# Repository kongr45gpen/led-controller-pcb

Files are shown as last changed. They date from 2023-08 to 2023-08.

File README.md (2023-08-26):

# led-controller-pcb

A PCB to control LEDs (up to 5 channels) using PWM, based on an Espressif ESP32-C6 development board.

Do you want to control your LEDs through Wi-Fi, Bluetooth or Zigbee, but you don't have 100€ lying around? This project is for you!
## Images

 

## Features

- 5 PWM **output channels**
- 5 **switch MOSFETS** (up to 8A)
- VIN **up to 28V**
- ESP32-C6 controllable through **USB, Wi-Fi, Bluetooth 5 (LE), IEEE 802.15.4**
- Support for RGB, RGBW, RGBWW/CW, WS2812B, and other configurations
- Control through MQTT, HomeAssistant
- **Non**-isolated input
- Fully open-source software and hardware
- 6.25 × 5 cm
- Not battle tested, so might stop working randomly

## Software

You can write your software using any framework you prefer. This board is built and will work out of the box for the [kongr45gpen/ledstripesp32](https://github.com/kongr45gpen/ledstripesp32) project specifically.

## Bill of Materials

This board is meant to function as a **controller** (generating low-power PWM signals from a network/wired input), as a **dimmer** (switching high-power LED lights on/off based on the input signal) or both.

The **controller** function is based on the [ESP32-C6-DevKitC-1](https://docs.espressif.com/projects/espressif-esp-dev-kits/en/latest/esp32c6/esp32-c6-devkitc-1/index.html) development board, but other ESP32 development boards should be also usable (not tested).

The **dimmer** function relies on a few MOSFETs to control the current flow from the output.

The rest of the components are mostly optional and slightly improve the functionality of the board (connectors, pull-down resistors etc). The user can choose whichever components they need and assemble the board to their preference. Many components (e.g. DC barrel jack, headers, passives) may be replaceable with cheaper generic alternatives.

An all-around configuration should cost ~20€, and adding a screen, voltage regulator and detachable headers should move the price up to ~35€.

A total project cost for a simple RGB led control system could be: 5m 5050 12V RGB LED strip (10€) + 12V 1A power supply (10€) + PCB (6€) + components (20€) = 46€.

With example parts and prices from Mouser:

| Ref | Part | Qu.| CONT. | DIM. | Description | Price |
| :-- | :--- | :---: | :---: | :----: | --- | ----: |
| Brd1 | 4-pin I2C SSD1306 | 1 | ❓ | | Debugging info screen | 3€ |
| C1 | C 100nF 0603 (1608 metric) | 1 | | ✔️ | Decoupling capacitor | [0.1€](https://www.mouser.com/ProductDetail/581-04026D104KAT4A) |
| J1 | CUI PJ-063AH | 1 | | ❓ | VIN Barrel connector | [1.5€](https://www.mouser.com/ProductDetail/490-PJ-063AH) |
| J2 | Molex SL 171971-0002 | 1 | | ❓ | VIN Header connector | [0.8€](https://www.mouser.com/ProductDetail/Molex/171971-0002?qs=lc2O%252BfHJPVZiIVvtLkRJ0A%3D%3D) |
| J3 | Molex SL 171971-0007 | 1 | ❓ | ❓ | PWM input/output connector (5 pins + GND) | [1.5€](https://www.mouser.com/ProductDetail/Molex/171971-0007?qs=lc2O%252BfHJPVYTelce0YNW%252BQ%3D%3D) |
| J4 | 5mm 6-pin screw terminal | 1 | | ✔️ | Power output (5 pins + VDD) | [0.9€](https://www.mouser.com/ProductDetail/490-TB003-500-P06BE) |
| J5 | Molex SL 171971-0003 | 1 | ❓ | | Addressable LED output | [1.1€](https://www.mouser.com/ProductDetail/Molex/171971-0003?qs=lc2O%252BfHJPVYq9zLgxhm5jg%3D%3D) |
| LED1..5 | 0805 (2012 metric) LED | 5 | ❓ | ❓ | Indicator LEDs for PWM | [1.25€](https://www.mouser.com/ProductDetail/859-LTST-C170KFKT) |
| LED\_POWER1 | 0805 (2012 metric) LED | 1 | | ❓ | Indicator LED for VDD | [0.25€](https://www.mouser.com/ProductDetail/859-LTST-C170KFKT) |
| Q1..5 | IRLTS6342 (N-MOSFET) | 5 | | ✔️ | Control transistors (use as many as needed) | [1.7€](https://www.mouser.com/ProductDetail/Infineon-Technologies/IRLTS6342TRPBF?qs=8jYDHybYAxsDJhh9ct3B2Q%3D%3D) |
| R1..6 | R 15kΩ 0603 (1608 metric) | 6 | | ❓ | LED series resistors (use as many as needed) | [0.1€](https://www.mouser.com/ProductDetail/603-RC0603FR-0715KL) |
| Rpd1..5 | R 100kΩ 0603 (1608 metric) | 5 | ❓ | ❓ | Pull-down resistors to keep output off when disconnected | [0.1€](https://www.mouser.com/ProductDetail/603-RC0402FR-07100KL) |
| SW1 | PTS647SM70SMTR2LFS | 1 | ❓ | | ESP32 input switch | [0.2€](https://www.mouser.com/ProductDetail/CK/PTS647SM70SMTR2LFS?qs=PqoDHHvF64%252Bxl5nIb9IaOw%3D%3D) |
| U1 | ESP32-C6-DevKitC-1 | 1 | ✔️ | | ESP32 development kit | [8€](https://www.mouser.com/ProductDetail/356-ESP32C6DKC1N8) |
| VR1 | Wurth 1769405241 | 1 | ❓ | | Voltage regulator to provide 5V to ESP32 from VIN | [5€](https://www.mouser.com/ProductDetail/710-1769405241) |

### Extra Accessories

| Part | Quantity | CONTROLLER | DIMMER | Description | Price |
|---|:---:|:---:|:---:|---|---:|
| 4-pin header | 1 | ❓ |  | For screen (`Brd1`) | [0.7€](https://www.mouser.com/ProductDetail/200-CES10402TS) |
| 16-pin-header | 2 | ❓ | | For ESP32 (`U1`) | [5€](https://www.mouser.com/ProductDetail/200-CES11601TS) |
| Molex 14-60-0024 | 1 | | ❓ | Wire plug for `J2` | [0.4€](https://www.mouser.com/ProductDetail/538-14-60-0024) |
| Molex 14-60-0072 | 1 | ❓ | ❓ | Wire plug for `J3` | [1.5€](https://www.mouser.com/ProductDetail/538-14-60-0072) |
| Molex 14-56-7032 | 1 | ❓ | | Wire plug for `J5` | [0.7€](https://www.mouser.com/ProductDetail/538-14-56-7032) |

### Solder Bridges

Some solder bridges/solder jumpers may need to be soldered before any operation can take place.

| Ref | Pins | CONTROLLER | DIMMER | Description |
| :-- | :--: | :---: | :----: | :--- |
| JP1 | 3 | | ✔️ | Controls the source of `VDD` for the LED power output. Bridge 2-1 to connect to `5V`. Bridge 2-3 to connect to `VIN` (J1, J2). |
| JP2 | 3 | ❓ | | Controls the voltage source (typically 5V) for the addressable strip. Bridge 2-1 to connect to `5V`. Bridge 2-3 to connect to `VIN` (J1, J2). |
| JP3 | 2 | | ✔️ | Bridge to connect power ground with digital ground. **Must** solder for proper operation.  |
| JP4 | 2 | ❓ | | Bridge to connect VR1 output to 5V. Must solder to enable voltage regulation from VIN to ESP32 5V. Keep desoldered during debugging to prevent damaging your equipment.  |
| JPout1..5 | 2 | | ✔️ | Bridge to connect transistor outputs to output connector. You can alternatively wire a series resistor here for your output, if needed. |

### Example configurations

**All-in-one controller, from Wi-Fi to RGB LED strip**:
- C1, J1 to connect an external 12V power supply
- VR1 to convert the external 12V to 5V for the ESP32
- LED1..3, LED_POWER1, R1..3, R6 for debugging indicators
- Q1..3 as amplifiers
- Rpd1..3 to prevent lights from going up during boot
- J4 to screw LED strip wires
- U1 for control
- Bridge JP1 (2-3), JP3, JPout1..3. After uploading code, bridge JP4.
- BOM cost: **18€**

**Addressable strip controller with debugging screen**:
- No need for power input, as the ESP32 dev board already has USB-C connections
- U1 for control
- J5 connector to output addressable LED data
- J5 wire plug to solder on addressable LED
- Brd1 screen + 4-pin header to allow detaching it
- Bridge JP2 (2-1)
- BOM cost: **6€**

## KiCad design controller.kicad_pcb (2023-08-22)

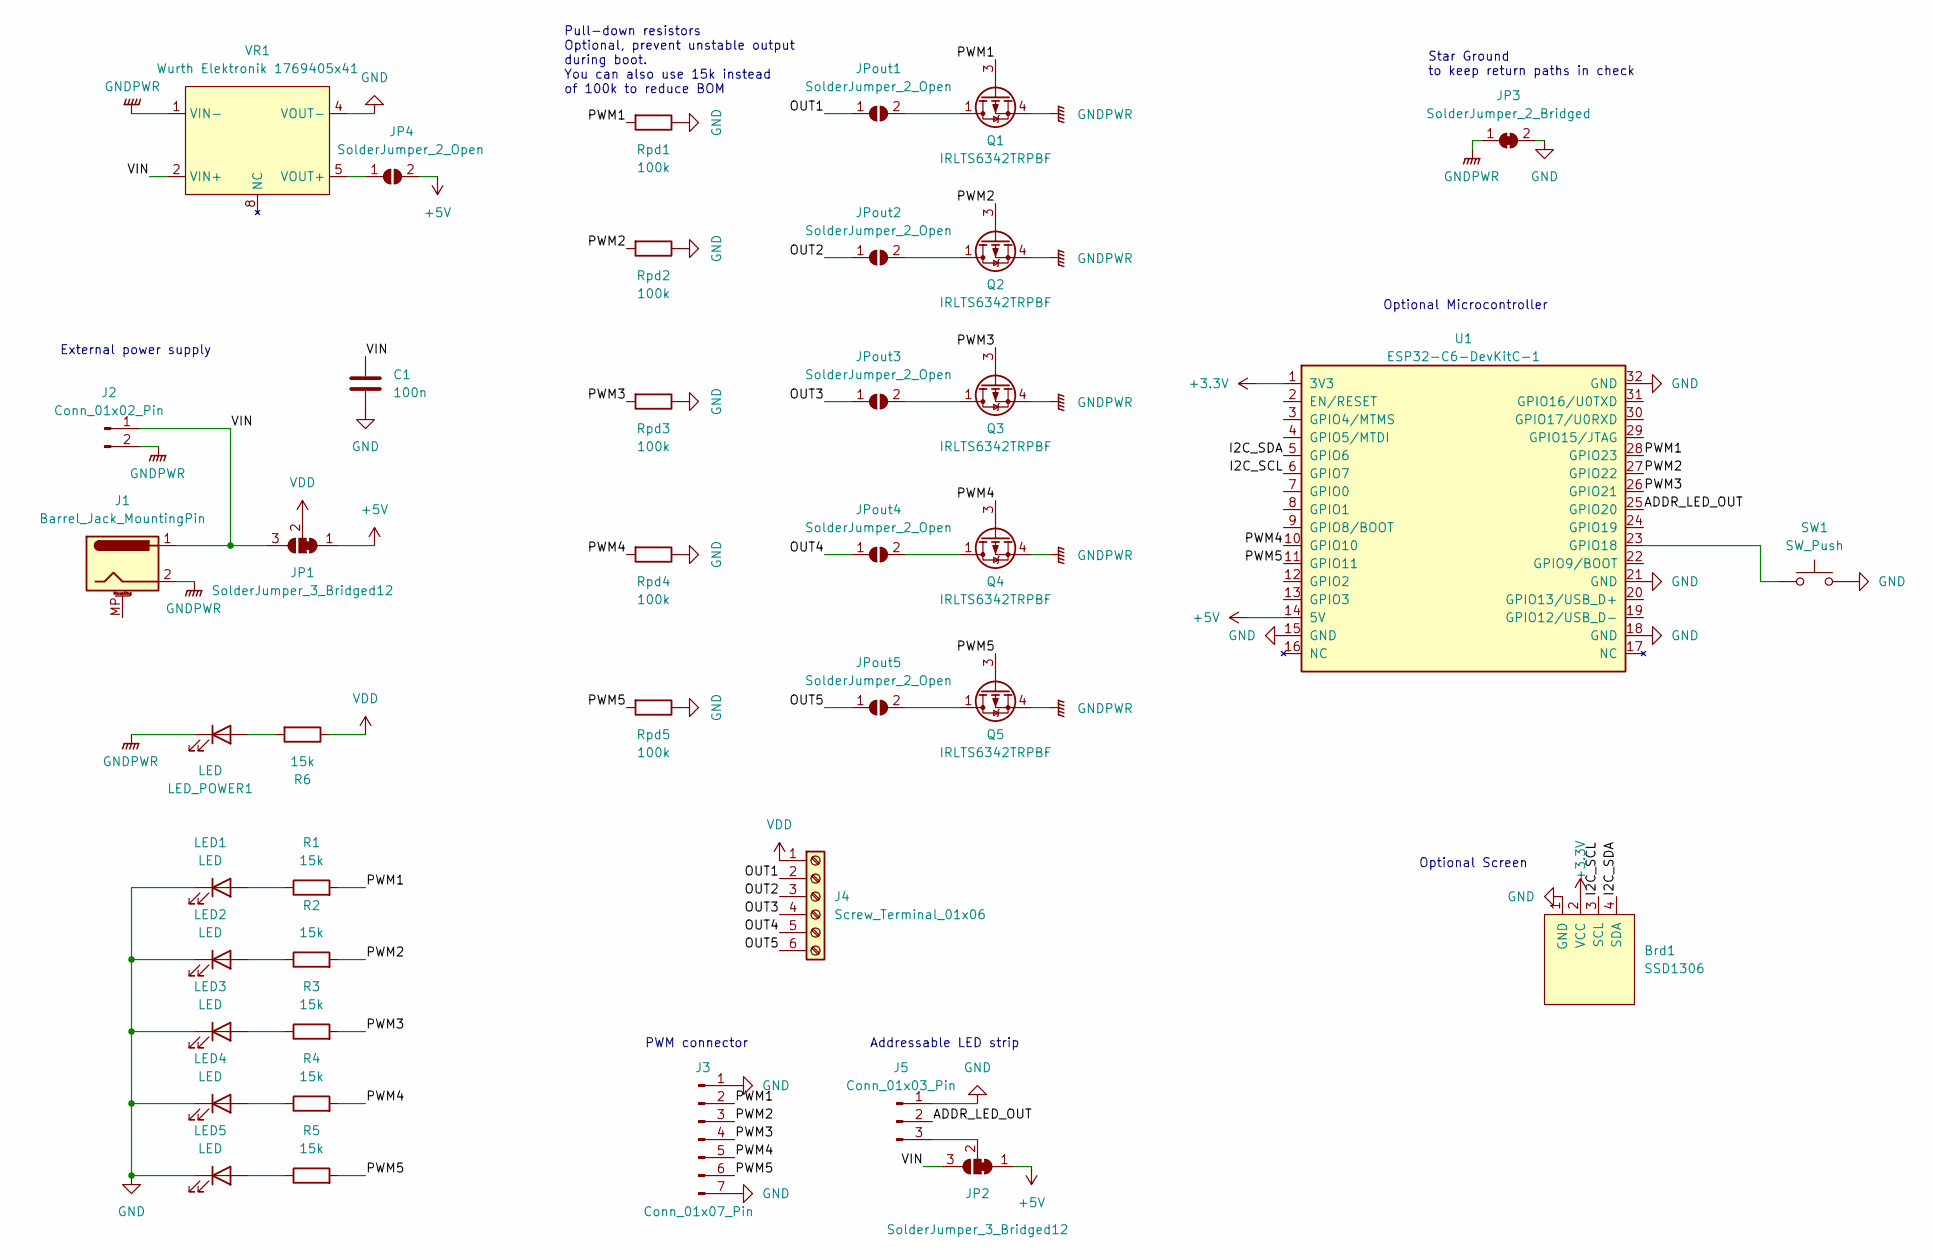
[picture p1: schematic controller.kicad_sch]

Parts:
Brd1: SSD1306; 128x64OLED
C1: 100n; C_0603_1608Metric_Pad1.08x0.95mm_HandSolder
J1: Barrel_Jack_MountingPin; BarrelJack_CUI_PJ-063AH_Horizontal_CircularHoles
J2: Conn_01x02_Pin; Molex_SL_171971-0002_1x02_P2.54mm_Vertical
J3: Conn_01x07_Pin; Molex_SL_171971-0007_1x07_P2.54mm_Vertical
J4: Screw_Terminal_01x06; TerminalBlock_RND_205-00005_1x06_P5.00mm_Horizontal
J5: Conn_01x03_Pin; Molex_SL_171971-0003_1x03_P2.54mm_Vertical
JP1, JP2: SolderJumper_3_Bridged12; SolderJumper-3_P1.3mm_Open_RoundedPad1.0x1.5mm_NumberLabels
JP3: SolderJumper_2_Bridged; SolderJumper-2_P1.3mm_Bridged2Bar_Pad1.0x1.5mm
JP4: SolderJumper_2_Open; SolderJumper-2_P1.3mm_Open_RoundedPad1.0x1.5mm
JPout1, JPout2, JPout3, JPout4, JPout5: SolderJumper_2_Open; SolderJumper-2_P1.3mm_Open_TrianglePad1.0x1.5mm
LED1, LED2, LED3, LED4, LED5: LED; LED_0805_2012Metric_Pad1.15x1.40mm_HandSolder
LED_POWER1: LED; LED_0805_2012Metric_Pad1.15x1.40mm_HandSolder
Q1, Q2, Q3, Q4, Q5: IRLTS6342TRPBF; TSOP-6_1.65x3.05mm_P0.95mm
R1, R2, R3, R4, R5, R6: 15k; R_0603_1608Metric_Pad0.98x0.95mm_HandSolder
Rpd1, Rpd2, Rpd3, Rpd4, Rpd5: 100k; R_0603_1608Metric_Pad0.98x0.95mm_HandSolder
SW1: SW_Push; SWITCH-4
U1: ESP32-C6-DevKitC-1
VR1: Wurth Elektronik 1769405x41; 1769405x41

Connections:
+3.3V: Brd1.2 (VCC), U1.1 (3V3)
+5V: JP1.1 (A), JP2.1 (A), JP4.2 (B), U1.14 (5V)
/ADDR_LED_OUT: J5.2, U1.25 (GPIO20)
/I2C_SCL: Brd1.3 (SCL), U1.6 (GPIO7)
/I2C_SDA: Brd1.4 (SDA), U1.5 (GPIO6)
/OUT1: J4.2, JPout1.1 (A)
/OUT2: J4.3, JPout2.1 (A)
/OUT3: J4.4, JPout3.1 (A)
/OUT4: J4.5, JPout4.1 (A)
/OUT5: J4.6, JPout5.1 (A)
/PWM1: J3.2, Q1.3 (G), R1.2, Rpd1.2, U1.28 (GPIO23)
/PWM2: J3.3, Q2.3 (G), R2.2, Rpd2.2, U1.27 (GPIO22)
/PWM3: J3.4, Q3.3 (G), R3.2, Rpd3.2, U1.26 (GPIO21)
/PWM4: J3.5, Q4.3 (G), R4.2, Rpd4.2, U1.10 (GPIO10)
/PWM5: J3.6, Q5.3 (G), R5.2, Rpd5.2, U1.11 (GPIO11)
/VIN: C1.1, J1.1, J2.1, JP1.3 (B), JP2.3 (B), VR1.2 (VIN+)
GND: Brd1.1 (GND), C1.2, J3.1, J3.7, J5.1, JP3.2 (B), LED1.1 (K), LED2.1 (K), LED3.1 (K), LED4.1 (K), LED5.1 (K), Rpd1.1, Rpd2.1, Rpd3.1, Rpd4.1, Rpd5.1, SW1.2, SW1.4, U1.15 (GND), U1.18 (GND), U1.21 (GND), U1.32 (GND), VR1.4 (VOUT-)
GNDPWR: J1.2, J2.2, JP3.1 (A), LED_POWER1.1 (K), Q1.4 (S), Q2.4 (S), Q3.4 (S), Q4.4 (S), Q5.4 (S), VR1.1 (VIN-)
unnamed: J5.3, JP2.2 (C)
unnamed: JP4.1 (A), VR1.5 (VOUT+)
unnamed: JPout1.2 (B), Q1.1 (D), Q1.2 (D), Q1.5 (D), Q1.6 (D)
unnamed: JPout2.2 (B), Q2.1 (D), Q2.2 (D), Q2.5 (D), Q2.6 (D)
unnamed: JPout3.2 (B), Q3.1 (D), Q3.2 (D), Q3.5 (D), Q3.6 (D)
unnamed: JPout4.2 (B), Q4.1 (D), Q4.2 (D), Q4.5 (D), Q4.6 (D)
unnamed: JPout5.2 (B), Q5.1 (D), Q5.2 (D), Q5.5 (D), Q5.6 (D)
unnamed: LED1.2 (A), R1.1
unnamed: LED2.2 (A), R2.1
unnamed: LED3.2 (A), R3.1
unnamed: LED4.2 (A), R4.1
unnamed: LED5.2 (A), R5.1
unnamed: LED_POWER1.2 (A), R6.2
unnamed: SW1.1, SW1.3, U1.23 (GPIO18)
VDD: J4.1, JP1.2 (C), R6.1

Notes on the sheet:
External power supply
Star Ground to keep return paths in check
Pull-down resistors Optional, prevent unstable output during boot. You can also use 15k instead of 100k to reduce BOM
Addressable LED strip
Optional Microcontroller
Optional Screen
PWM connector

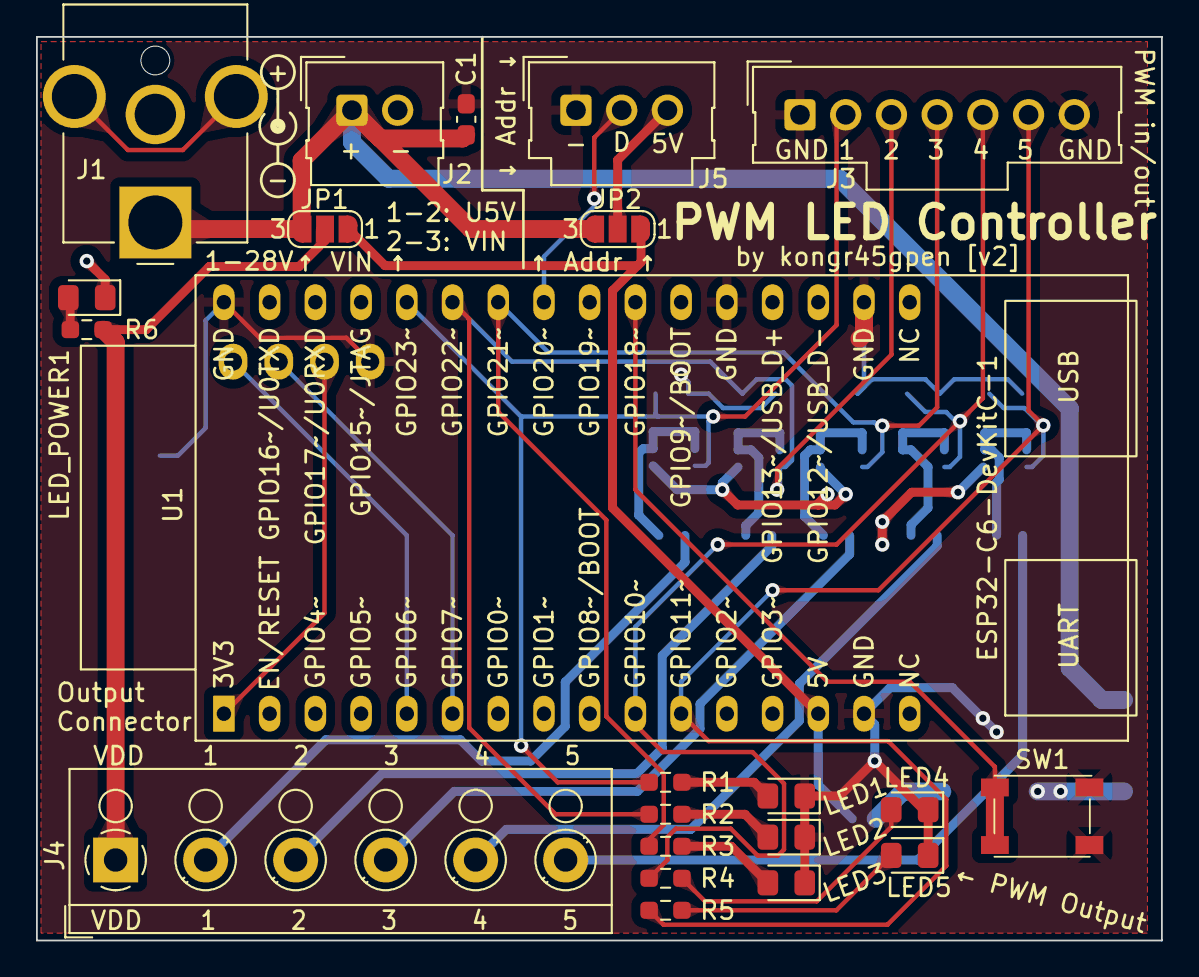
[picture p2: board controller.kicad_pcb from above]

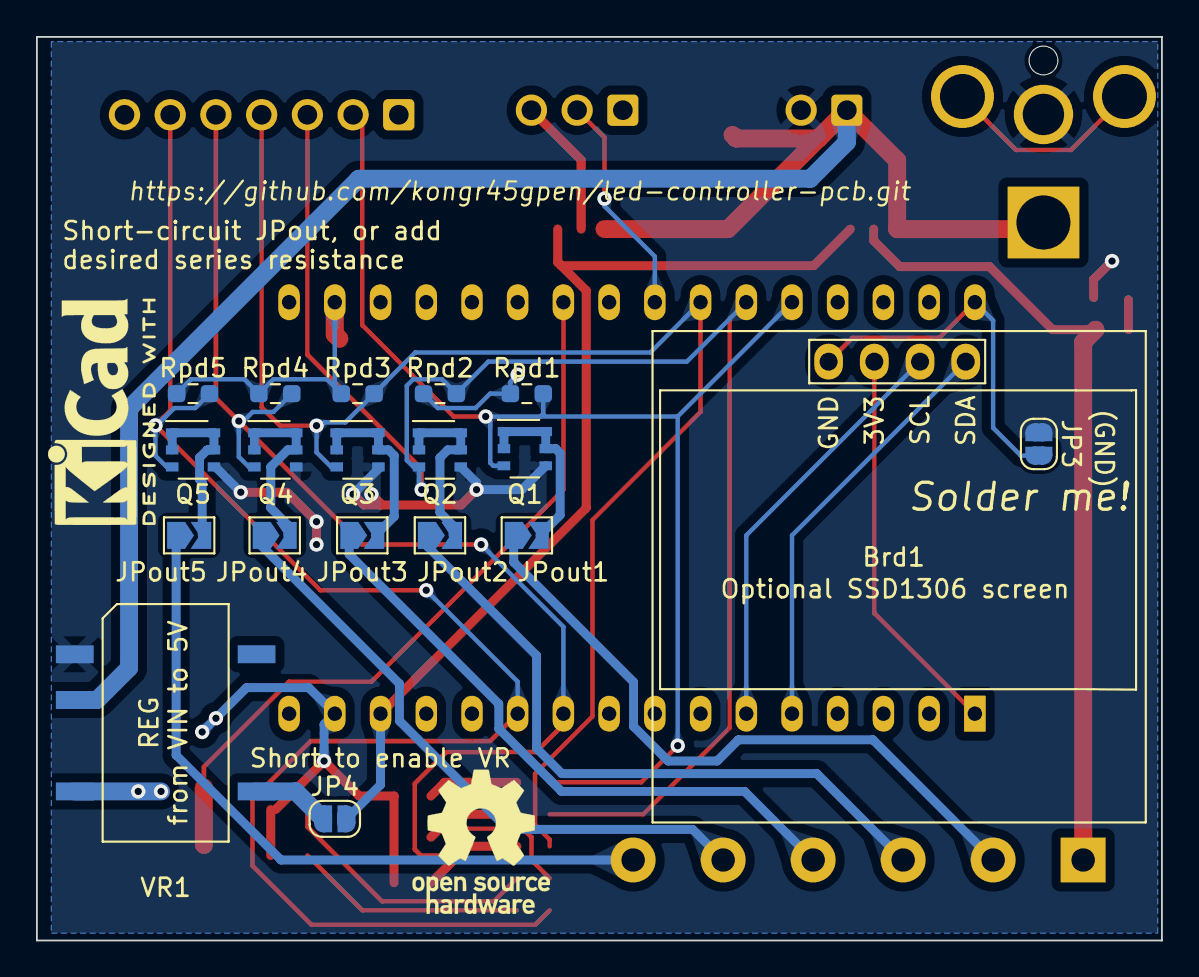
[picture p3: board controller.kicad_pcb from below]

Board: 2 copper layers, 62.5 x 50.2 mm, 41 parts (19 on the bottom side), 33 nets.

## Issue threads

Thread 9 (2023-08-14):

Fix footprint of switch

kongr45gpen, 2023-08-14:

Closed 2023-08-14.

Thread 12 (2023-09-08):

Revert connectors

kongr45gpen, 2023-09-08:
The connectors should be rotated 180°, so that the prongs to unlock look at the outer side of the PCB and are easier to access.

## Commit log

2023-07-09 Initial routing
    [controller.kicad_sch]
2023-07-09 Beautify silkscreen
    [controller.kicad_pcb]
2023-07-09 Add button
    [controller.kicad_pcb, controller.kicad_sch]
2023-07-09 Add figures
    [controller.kicad_pcb]
2023-07-09 Increase board height to fit barrel jack pin
    [controller.kicad_pcb]
2023-07-10 Commit unsaved changes
    [controller.kicad_sch]
2023-08-14 Updates for PCB v2
    [controller.kicad_pcb, controller.kicad_sch]
2023-08-14 Fix switch footprint
    [controller.kicad_sch]
2023-08-14 Complete routing
    [controller.kicad_pcb, controller.kicad_sch]
2023-08-22 Add teardrops and beautify some traces
    [controller.kicad_pcb]
2023-08-26 Add some missing information about solder bridges
